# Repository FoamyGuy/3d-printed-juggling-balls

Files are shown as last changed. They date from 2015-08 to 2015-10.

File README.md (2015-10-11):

OpenScad Juggling Ball
----------------------
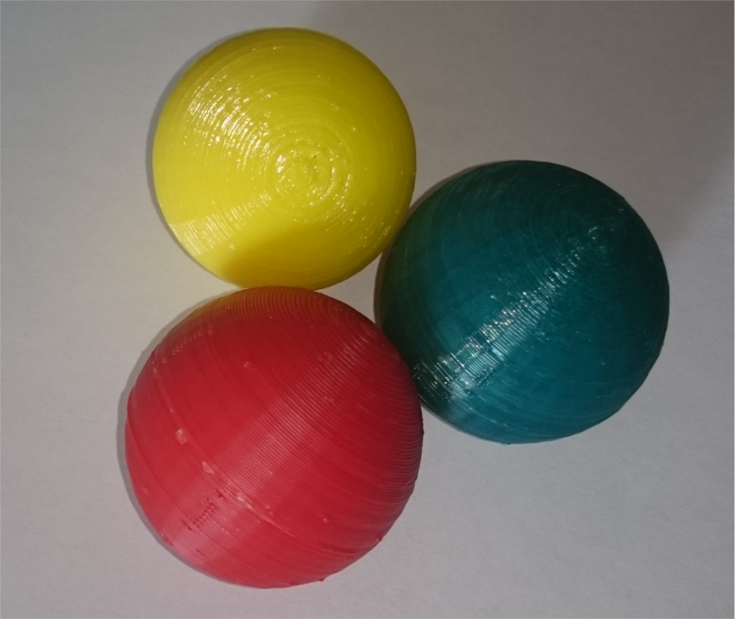
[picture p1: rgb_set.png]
RGB Set


One ball is made up of 3 total parts. Two halves and one threaded rod to connect them together.

So far the metal insert version is holding up much better under use than the 100% plastic ones.

### Brass fastener version:

The plastic threaded rods kept breaking when I drop the balls and they hit too hard. I've been playing around with these threaded inserts lately and figured this would be a good use for them. I put one in each half and then cut down a small threaded rod to serve as the connector pin.

I used 8-32 threaded rod with matching [brass press-fit expansion inserts](http://www.mcmaster.com/#standard-threaded-inserts/=zbno3k)

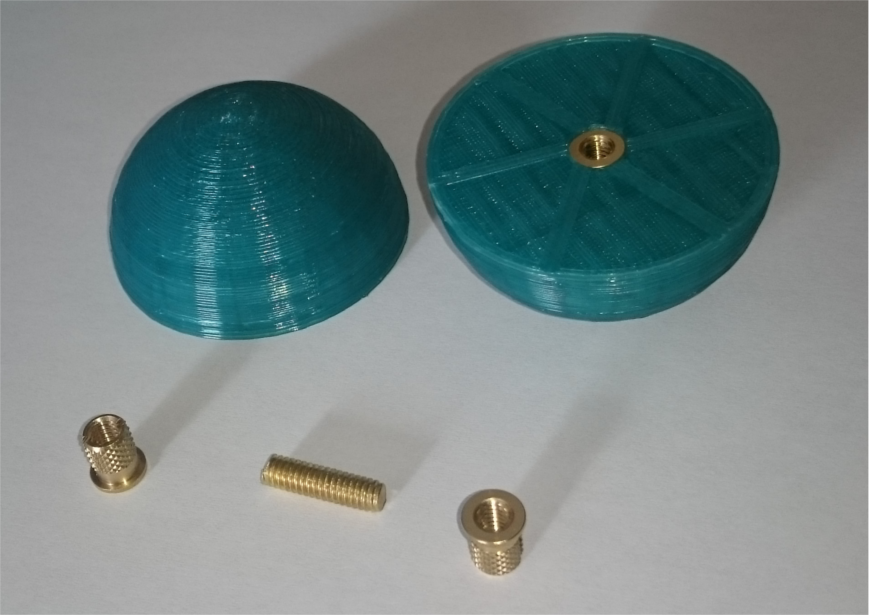
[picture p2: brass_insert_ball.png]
Brass Inserts


### 100% printed version:

Big thanks to aubenc. The threaded rod comes from [his thing](http://www.thingiverse.com/thing:8796)

The STL is a 44mm diameter ball I like this size but you are free to tweak it in the scad file if you want.

The star pattern on the bottom of the half ball makes it a bit easier to pry the peace off of the build plate for me (LulzBot Mini).

The threaded rods are set to 2mm outer diameter smaller than the whole. For me the rods fit pretty loosely, but with both halves screwed together it creates a firm connection.

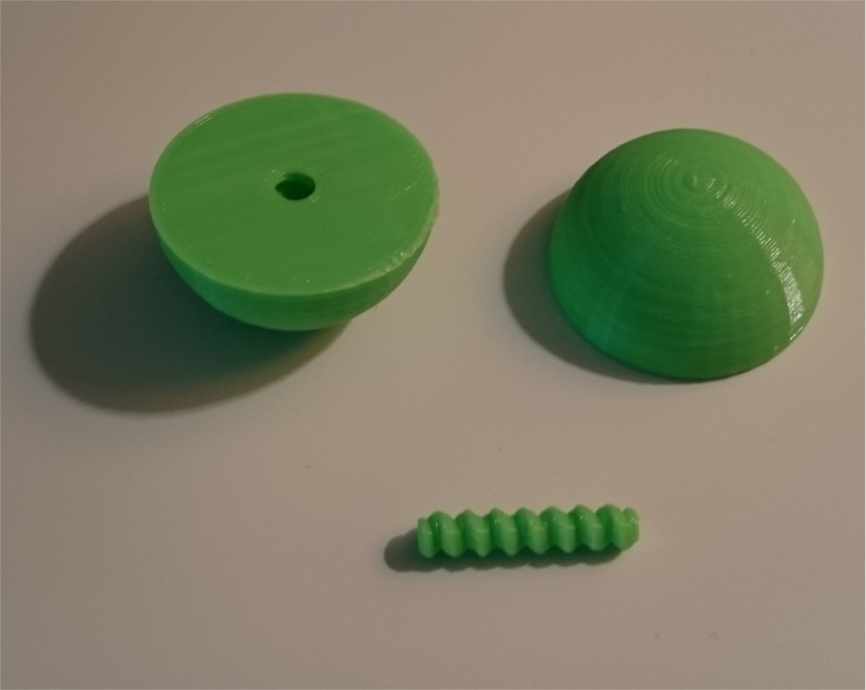
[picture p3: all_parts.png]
Disassembled ball


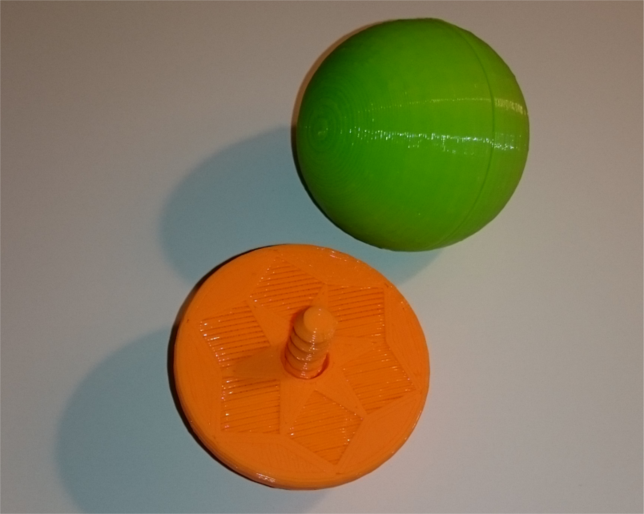
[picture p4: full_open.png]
1 Complete and 1 Half


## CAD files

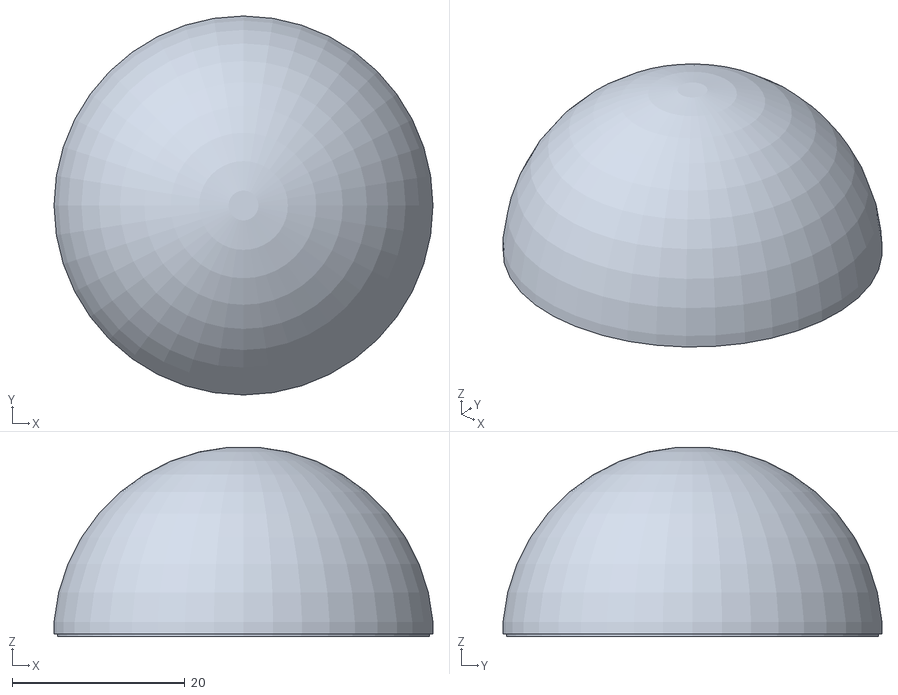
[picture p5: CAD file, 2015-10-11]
all_printed/44mm_half_ball_threaded_big_rod.stl
43.9 x 43.9 x 21.9

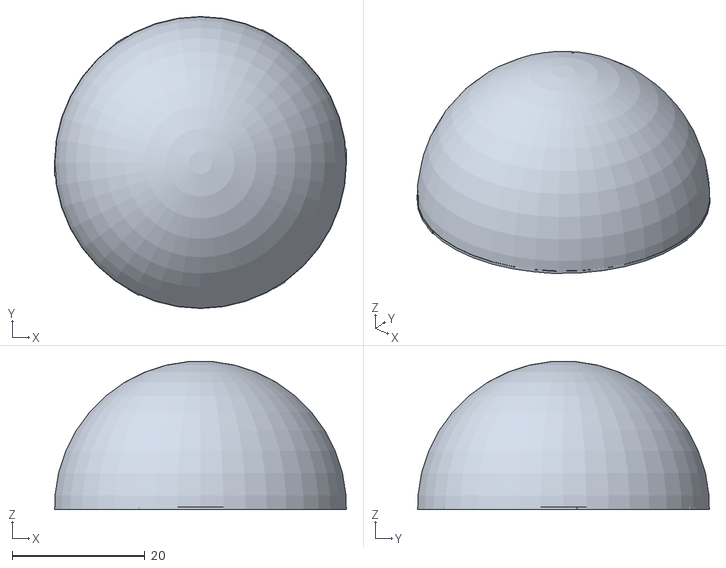
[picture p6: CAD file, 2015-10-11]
metal_fasteners/JugglingBall_Threaded_insert.stl
44.0 x 44.0 x 22.3

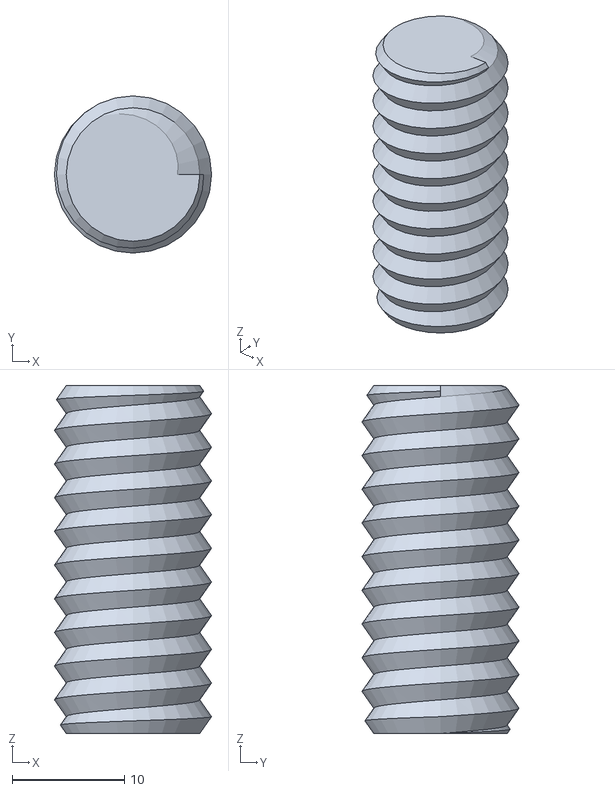
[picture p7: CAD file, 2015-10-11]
all_printed/threaded_rod_big.stl
14.0 x 14.0 x 31.0

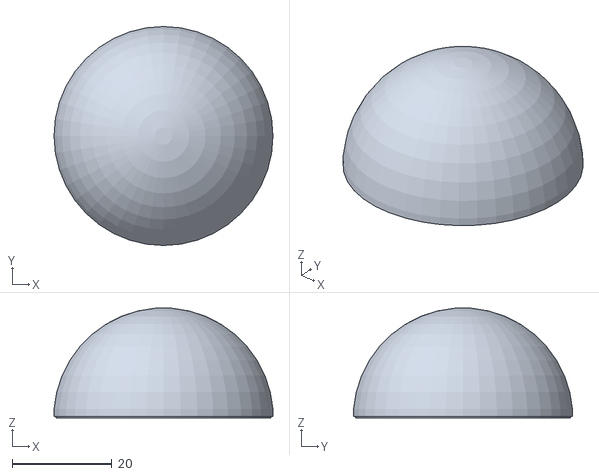
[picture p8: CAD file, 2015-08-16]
all_printed/44mm_half_ball_threaded.stl
43.9 x 43.9 x 21.9

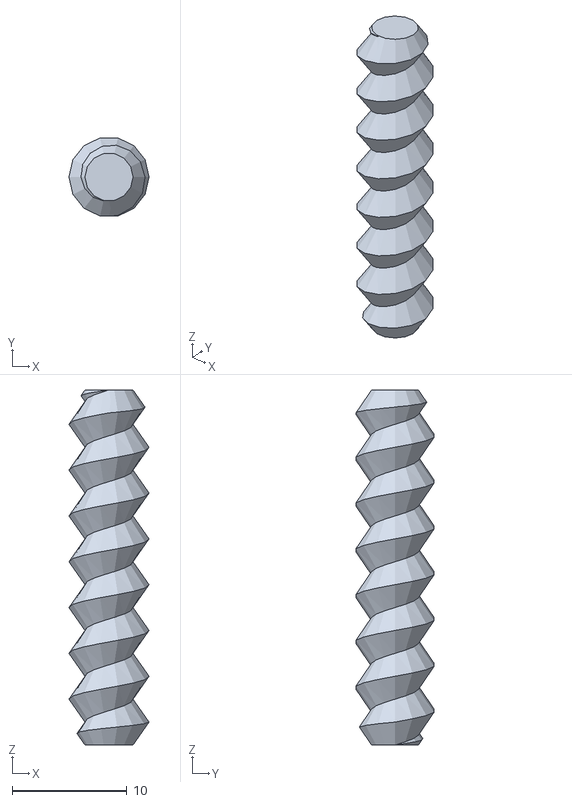
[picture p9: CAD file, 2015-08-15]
all_printed/threaded_rod.stl
7.00 x 6.82 x 31.0

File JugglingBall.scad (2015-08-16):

include <polyScrewThread_r1.scad>
$fn=40;

/****************
* Modules
*****************/
module countersink_end(chg,cod,clf,crs,hg)
{
    translate([0,0,-0.1])
    cylinder(h=chg+0.01, 
             r1=cod/2, 
             r2=cod/2-(chg+0.1)*cos(clf)/sin(clf),
             $fn=floor(cod*PI/crs), center=false);
}

/**********
* Variables
***********/
BALL_DIAMETER = 44;
THREAD_HOLE_DIAMETER = 9;
THREAD_HOLE_DEPTH = 16;

ROD_DIAMETER = 7;
ROD_HEIGHT = (THREAD_HOLE_DEPTH * 2) + 1;


/************
* Main Render
*************/
difference(){
    sphere(d=BALL_DIAMETER);
    
    //Cut the floor
    translate([-1*(BALL_DIAMETER/2), 
                -1*(BALL_DIAMETER/2), 
                -1*(BALL_DIAMETER)]){
        cube([BALL_DIAMETER,BALL_DIAMETER,BALL_DIAMETER]);
    }
    
    // Thread hole
    screw_thread(THREAD_HOLE_DIAMETER,4,55,
                 THREAD_HOLE_DEPTH,PI/2,2);
    
    
    countersink_end(4,THREAD_HOLE_DIAMETER,55,0.5,0);
     
    // 1 layer lip to aide removing from build plate.
     difference(){
        cylinder(d=BALL_DIAMETER+2, h=.3);
        cylinder(d=BALL_DIAMETER-1, h=.3);
     }
     
     
     // 1 layer cutouts to aide removing from build plate.
     for(r=[0:(360/6):360]){
        rotate([0,0,r]){
           translate([4,4,0]){
                cube([10,10,.3]);
           }
        }
    }
     
} 


// Threaded Rod Connector
//screw_thread(ROD_DIAMETER,4,55,ROD_HEIGHT,PI/2,2);

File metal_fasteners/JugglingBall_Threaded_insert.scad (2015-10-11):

include <polyScrewThread_r1.scad>
$fn=40;

/**********
* Variables
***********/
BALL_DIAMETER = 44;
INSERT_DRILL_DIAMETER = 5.556;
INSERT_DRILL_DEPTH = 10;



/****************
* Modules
*****************/
module threaded_insert_cutout(h=INSERT_DRILL_DEPTH){
    cylinder(r=(INSERT_DRILL_DIAMETER/2),h, $fn=30);
}

module countersink_end(chg,cod,clf,crs,hg)
{
    translate([0,0,-0.1])
    cylinder(h=chg+0.01, 
             r1=cod/2, 
             r2=cod/2-(chg+0.1)*cos(clf)/sin(clf),
             $fn=floor(cod*PI/crs), center=false);
}


module peel_off_cutout(){
    
    difference(){
        cylinder(d=BALL_DIAMETER, h=.38);
        cylinder(d=BALL_DIAMETER-3, h=.38);
     }
             
     
    difference(){
        union(){
            for(r=[0:(360/6):360]){
                rotate([0,0,r]){
                   translate([0,0,0]){
                        cube([BALL_DIAMETER/2,2,.38]);
                   }
                }
            }
            
            // buffer around insert
            cylinder(d=INSERT_DRILL_DIAMETER+2, h=.38);
        }

        threaded_insert_cutout(h=INSERT_DRILL_DEPTH);
        
    }
    

     

    
}


/************
* Main Render
*************/
translate([0,0,.38]){
    difference(){
        sphere(d=BALL_DIAMETER);
        
        //Cut the floor
        translate([-1*(BALL_DIAMETER/2), 
                    -1*(BALL_DIAMETER/2), 
                    -1*(BALL_DIAMETER)]){
            cube([BALL_DIAMETER,BALL_DIAMETER,BALL_DIAMETER]);
        }
        
        // Threaded Insert hole
        threaded_insert_cutout(h=INSERT_DRILL_DEPTH);

         
    }
}

peel_off_cutout();

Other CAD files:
all_printed/JugglingBall.scad
all_printed/polyScrewThread_r1.scad

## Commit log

2015-08-16 bit of cleanup
    [JugglingBall.scad]
2015-08-16 new ball stl
    [44mm_half_ball_threaded.stl]
2015-10-11 adding brass fastener version
    [44mm_half_ball_threaded.stl, 44mm_half_ball_threaded_big_rod.stl, JugglingBall.scad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]
